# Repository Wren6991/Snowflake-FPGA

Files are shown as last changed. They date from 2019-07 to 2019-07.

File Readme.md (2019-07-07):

Snowflake FPGA HAT
==================

As an experiment, I am designing a PCB using only my Pi 4 4GB. Any other machine is off-limits. This includes

- Schematic entry
- Layout
- Datasheets and reference material
- Background Twitter browsing
- Rendering PCB glamour shots:

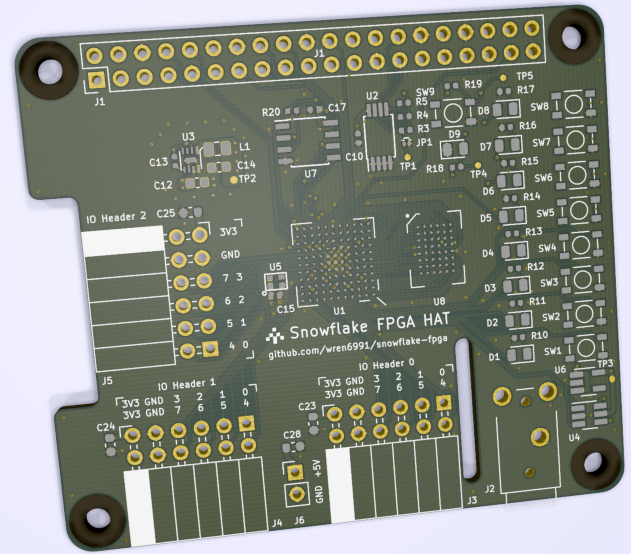
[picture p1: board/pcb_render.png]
Rendering of PCB


This is a HAT (Raspberry Pi addon board) with an iCE40 HX8k FPGA. The Pi can program the FPGA, and communicate with it via a UART, or a fast, bidirectional SDIO link. This project was spurred by the realisation that Pi 4 is a plausible FPGA development platform: faster processors, expanded memory and, above all, dramatic improvements in [Symbiotic EDA](https://www.symbioticeda.com/)'s open source design flows in the last few years.

[View schematic (PDF)](board/fpga_hat.pdf)

With the exception of the `datasheet/` directory (to which I do not lay claim), this repository is distributed under the [Apache-2.0 License](License).

Features
--------

- iCE40 HX8k
- 4 Mbit SRAM 16 bit wide, 10 ns access
- 4 Mbit flash for FPGA image and user data; dual I/O support
- 3 PMOD-compatible expansion headers
    - 8 3.3V IOs each, plus power and ground
    - 2 headers on one side, 1 on another; the two on one side have standard 0.9" spacing, allowing use of dual-PMOD boards
- Communication with host Pi:
    - UART
    - SPI for flash programming
    - SDIO for fast communications
    - FPGA reset, and configuration status (CDONE)
- 8 user pushbuttons and LEDs
- Reset button and configuration status LED
- Audio output via 3.5 mm jack (same audio circuit as Pi)

Tolerances
----------

Of the 121 balls on the FPGA's BGA package, I am using 120; the sole unconnected ball is VPP_FAST, which is used only for NVCM programming. This will make the layout exceptionally tight, which is part of the experiment! For a fighting chance, I am using JLCPCB to manufacture the prototype boards, rather than my usual iTead. Their tighter manufacturing tolerances should permit two traces between 0.3 mm pads on a 0.8 mm-pitch BGA, which allows the first 3 ranks of balls to be routed out on layer 1.

The capability requirements for this board are:

- Via drill 0.2 mm
- Via diameter 0.45 mm
- Copper min width 0.09 mm
- Copper-copper clearance 0.09 mm
- Solder mask expansion 0.05 mm

Stackup
-------

This is a 4-layer board.

- L1: signal, GND fill
- L2: GND plane
- L3: Power polygons (+5V, +3V3, +1V2)
- L4: signal, GND fill

All layers 1 oz/sqft copper. Assumed stacking for FR4 layers:

- L1-L2 0.2 mm prepreg
- L2-L3 1.2 mm core
- L3-L4 0.2 mm prepreg

These dimensions are not critical. Signal integrity will be improved by minimising separation of L1-L2, but none of the routing is impedance-controlled.

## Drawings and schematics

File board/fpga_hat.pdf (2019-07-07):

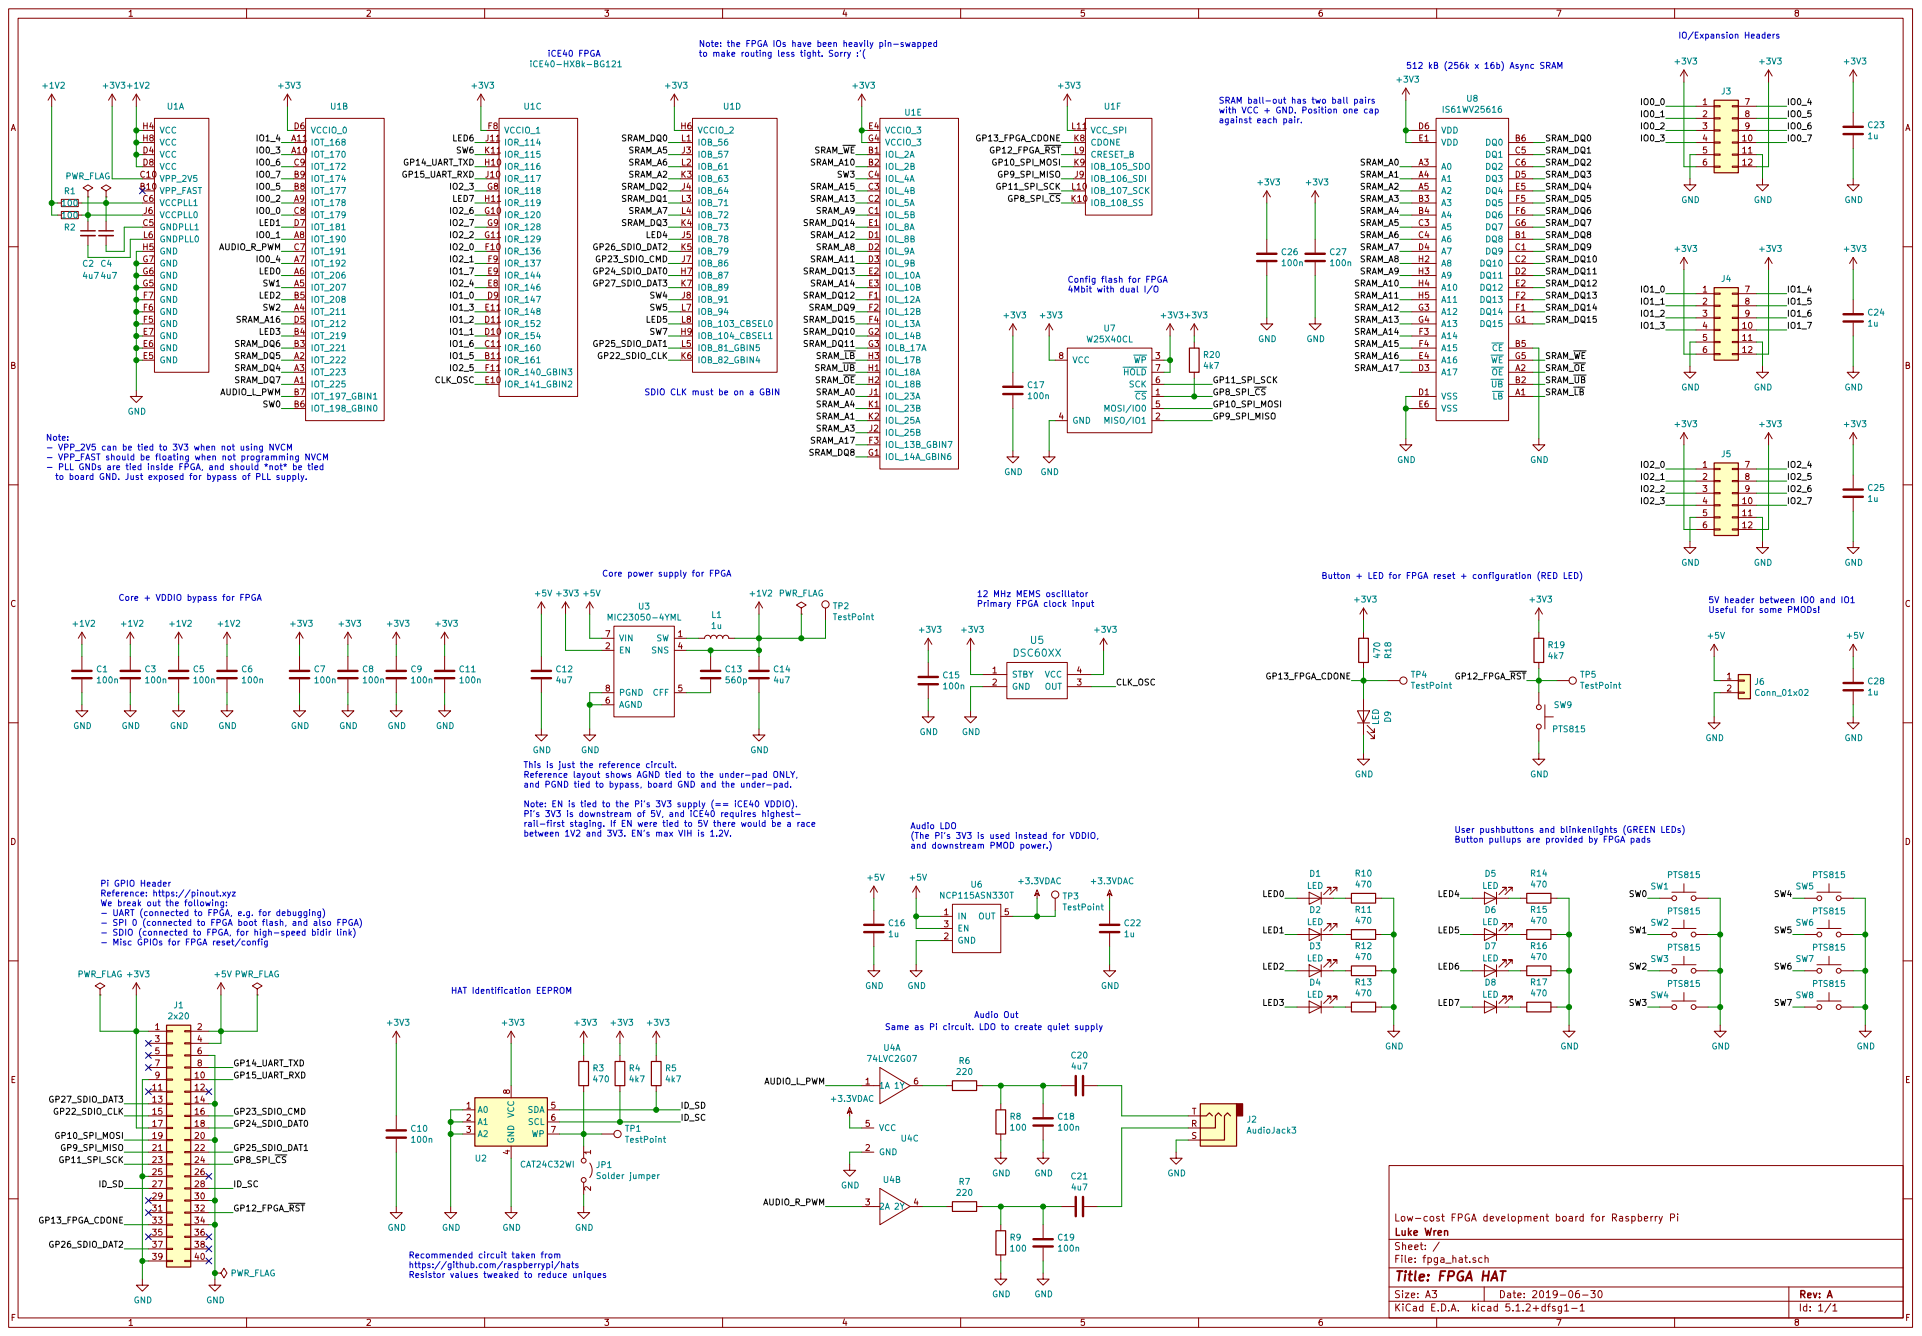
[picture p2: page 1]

to make routing less tight. Sorry :'( SDIO CLK must be on a GBIN

100n SRAM ball-out has two ball pairs
with VCC + GND. Position one cap
against each pair.

PWR_FLAG
to board GND. Just exposed for bypass of PLL supply. R1

GP11_SPI_SCK GP8_SPI_CS Config flash for FPGA
4Mbit with dual I/O
+3V3 GND

Note: - VPP_2V5 can be tied to 3V3 when not using NVCM

- VPP_FAST should be floating when not programming NVCM
- PLL GNDs are tied inside FPGA, and should *not* be tied

+1V2 Core power supply for FPGA

5V header between IO0 and IO1 Useful for some PMODs! C10

between 1V2 and 3V3. EN's max VIH is 1.2V. +5V GND

12 MHz MEMS oscillator Primary FPGA clock input
100n +3V3 GND

Reference layout shows AGND tied to the under-pad ONLY,
and PGND tied to bypass, board GND and the under-pad.

Note: EN is tied to the Pi's 3V3 supply (== iCE40 VDDIO).
Pi's 3V3 is downstream of 5V, and iCE40 requires highest-
rail-first staging. If EN were tied to 5V there would be a race

Button pullups are provided by FPGA pads Audio LDO
(The Pi's 3V3 is used instead for VDDIO,
1u +5V GND

SW4 SW5 SW6 SW7 User pushbuttons and blinkenlights (GREEN LEDs)

2x20 Pi GPIO Header Reference: https://pinout.xyz

We break out the following:
- UART (connected to FPGA, e.g. for debugging)
- SPI 0 (connected to FPGA boot flash, and also FPGA)
- SDIO (connected to FPGA, for high-speed bidir link)

4 SDA 5 SCL 6 WP 7 VCC

File: fpga_hat.sch Sheet: / Luke Wren

Recommended circuit taken from
https://github.com/raspberrypi/hats

Id: 1/1 Title: FPGA HAT

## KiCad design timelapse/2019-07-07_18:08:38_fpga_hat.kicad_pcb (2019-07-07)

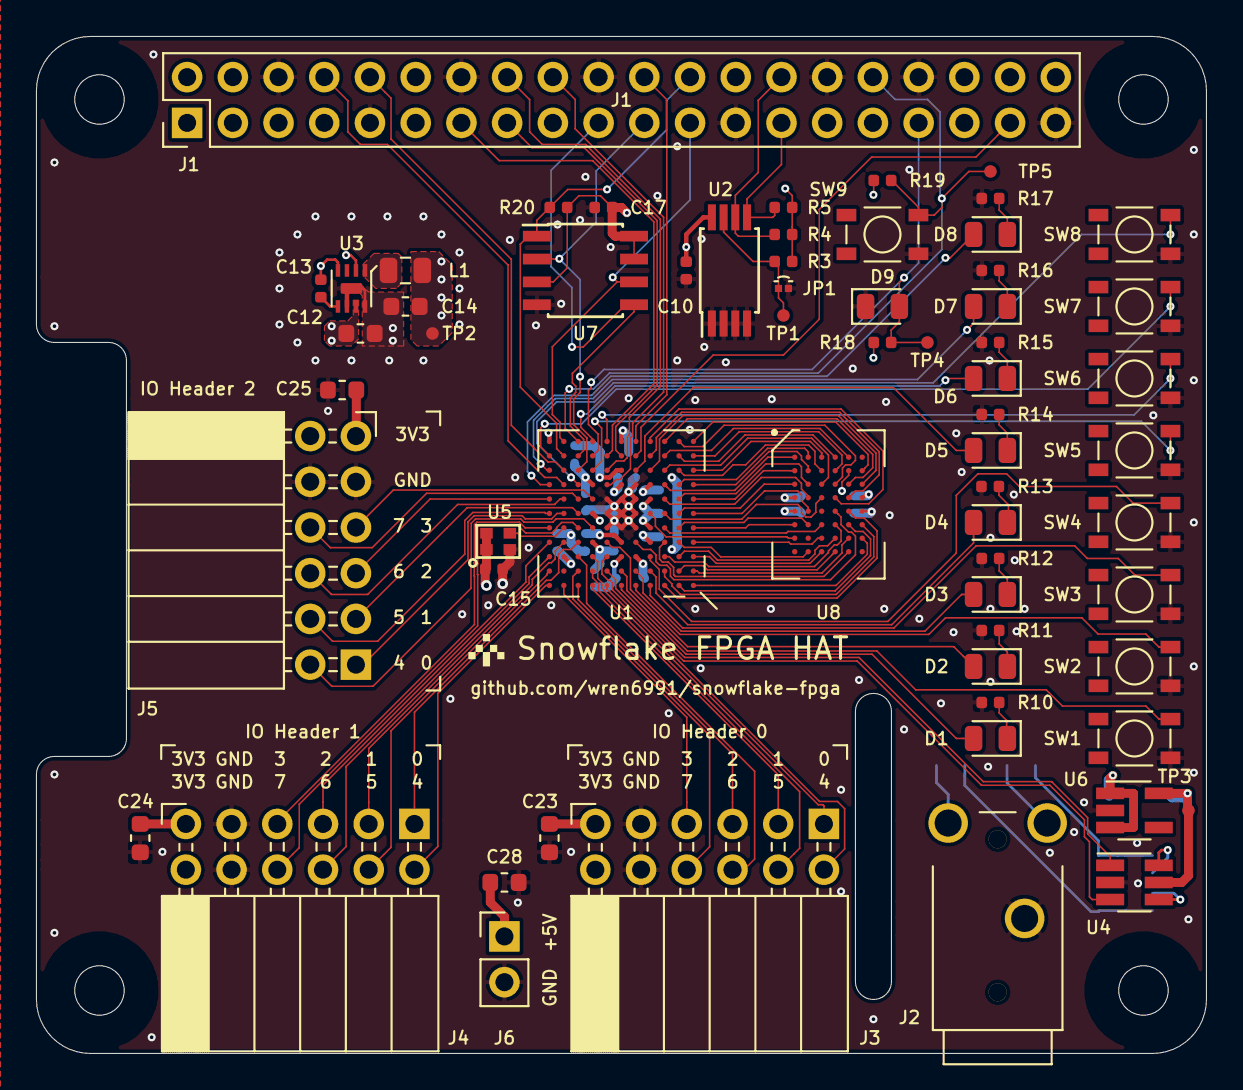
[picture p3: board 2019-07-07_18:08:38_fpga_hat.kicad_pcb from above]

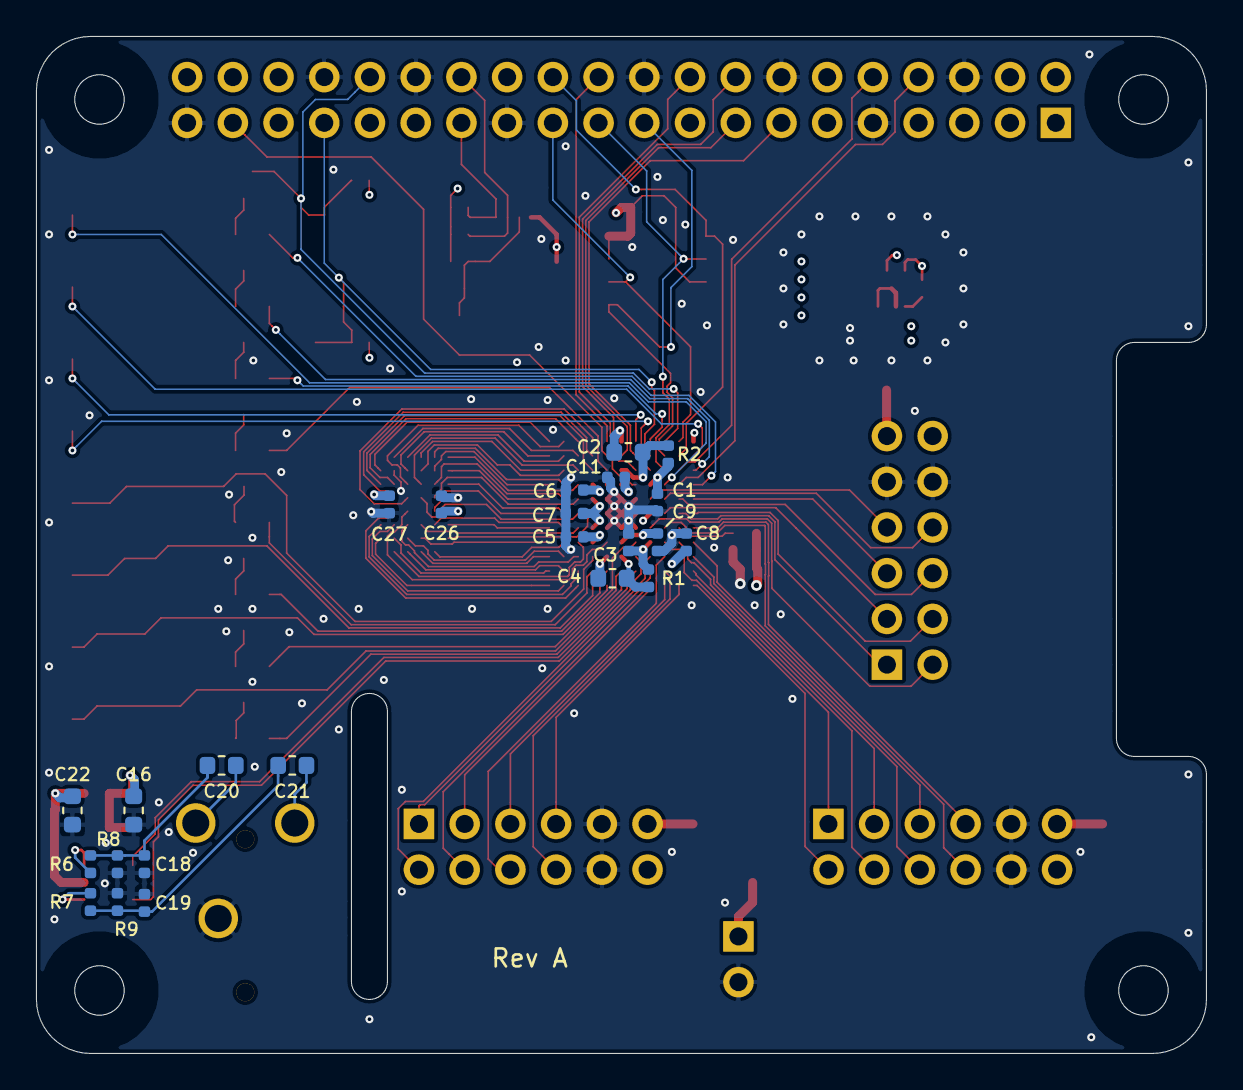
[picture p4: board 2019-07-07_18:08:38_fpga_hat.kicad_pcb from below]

Board: 4 copper layers, 65.0 x 56.5 mm, 87 parts (24 on the bottom side), 123 nets.

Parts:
C1, C3, C5, C6, C7, C8, C9, C10, C11, C15, C17, C18, C19, C26, C27: 100n; C_0402_1005Metric
C2, C4, C12, C14, C20, C21: 4u7; C_0603_1608Metric
C13: 560p; C_0402_1005Metric
C16, C22, C23, C24, C25, C28: 1u; C_0603_1608Metric
D1, D2, D3, D4, D5, D6, D7, D8, D9: LED; LED_0805_2012Metric
J1: 2x20; PinHeader_2x20_P2.54mm_Vertical
J2: AudioJack3; STX-3000_TRS_3.5mm
J3, J4, J5: Conn_02x06_Top_Bottom; PinSocket_2x06_P2.54mm_Horizontal
J6: Conn_01x02; PinHeader_1x02_P2.54mm_Vertical
JP1: Solder jumper; SOLDER_JUMP
L1: 1u; L_0805_2012Metric
R1, R2, R8, R9: 100; R_0402_1005Metric
R3, R10, R11, R12, R13, R14, R15, R16, R17, R18: 470; R_0402_1005Metric
R4, R5, R19, R20: 4k7; R_0402_1005Metric
R6, R7: 220; R_0402_1005Metric
SW1, SW2, SW3, SW4, SW5, SW6, SW7, SW8, SW9: PTS815
TP1, TP2, TP3, TP4, TP5: TestPoint; Testpoint_d0.7mm
U1: iCE40-HX8k-BG121; BGA-121_11x11_9.0x9.0mm
U2: CAT24C32WI; TSSOP-8_4.4x3mm_P0.65mm
U3: MIC23050-4YML; DFN8_2x2_0.5mm
U4: 74LVC2G07; SOT-23-6_Handsoldering
U5: DSC60XX; LGA4_1.6x1.2mm
U6: NCP115ASN330T; SOT-23-5_HandSoldering
U7: W25X40CL; SOIC-8_3.9x4.9mm_P1.27mm
U8: IS61WV25616; BGA-48_6x8_6.0x8.0mm

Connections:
+1V2: C1.1, C3.1, C5.1, C6.1, C13.1, C14.1, L1.2, R1.2, R2.2, TP2.1, U1.D4, U1.D8, U1.H4, U1.H8, U3.4
+3.3VDAC: C22.1, TP3.1, U4.5, U6.5
+3V3: C7.1, C8.1, C9.1, C10.1, C11.1, C15.1, C17.1, C23.1, C24.1, C25.1, C26.1, C27.1, J1.1, J1.17, J3.6, J3.12, J4.6, J4.12, J5.6, J5.12, R3.1, R4.1, R5.1, R18.2, R19.1, R20.1, U1.C10, U1.D6, U1.E4, U1.F8, U1.G4, U1.H6, U1.L11, U2.8, U5.1, U5.4, U7.3, U7.7, U7.8, U8.D6, U8.E1
+5V: C12.1, C16.1, C28.1, J1.2, J1.4, J6.1, U3.2, U3.7, U6.1, U6.3
/AUDIO_L_PWM: U1.B7, U4.1
/AUDIO_R_PWM: U1.C7, U4.3
/CLK_OSC: U1.E10, U5.3
/GP8_SPI_~CS: J1.24, R20.2, U1.K10, U7.1
/GP9_SPI_MISO: J1.21, U1.J9, U7.2
/GP10_SPI_MOSI: J1.19, U1.K9, U7.5
/GP11_SPI_SCK: J1.23, U1.L10, U7.6
/GP12_FPGA_~RST: J1.32, R19.2, SW9.1, TP5.1, U1.L9
/GP13_FPGA_CDONE: D9.2, J1.33, R18.1, TP4.1, U1.K8
/GP14_UART_TXD: J1.8, U1.H10
/GP15_UART_RXD: J1.10, U1.J10
/GP22_SDIO_CLK: J1.15, U1.K6
/GP23_SDIO_CMD: J1.16, U1.J7
/GP24_SDIO_DAT0: J1.18, U1.H7
/GP25_SDIO_DAT1: J1.22, U1.L5
/GP26_SDIO_DAT2: J1.37, U1.K5
/GP27_SDIO_DAT3: J1.13, U1.K7
/ID_SC: J1.28, R4.2, U2.6
/ID_SD: J1.27, R5.2, U2.5
/IO0_0: J3.1, U1.C8
/IO0_1: J3.2, U1.A8
/IO0_2: J3.3, U1.A9
/IO0_3: J3.4, U1.A10
/IO0_4: J3.7, U1.A7
/IO0_5: J3.8, U1.B8
/IO0_6: J3.9, U1.C9
/IO0_7: J3.10, U1.B9
/IO1_0: J4.1, U1.D9
/IO1_1: J4.2, U1.D10
/IO1_2: J4.3, U1.D11
/IO1_3: J4.4, U1.E11
/IO1_4: J4.7, U1.A11
/IO1_5: J4.8, U1.B11
/IO1_6: J4.9, U1.C11
/IO1_7: J4.10, U1.E9
/IO2_0: J5.1, U1.F10
/IO2_1: J5.2, U1.F9
/IO2_2: J5.3, U1.G11
/IO2_3: J5.4, U1.G8
/IO2_4: J5.7, U1.E8
/IO2_5: J5.8, U1.F11
/IO2_6: J5.9, U1.G10
/IO2_7: J5.10, U1.G9
/LED0: D1.2, U1.A6
/LED1: D2.2, U1.D7
/LED2: D3.2, U1.B5
/LED3: D4.2, U1.B4
/LED4: D5.2, U1.J5
/LED5: D6.2, U1.L8
/LED6: D7.2, U1.J11
/LED7: D8.2, U1.H11
/SRAM_A0: U1.J1, U8.A3
/SRAM_A1: U1.K2, U8.A4
/SRAM_A2: U1.K3, U8.A5
/SRAM_A3: U1.J2, U8.B3
/SRAM_A4: U1.K1, U8.B4
/SRAM_A5: U1.J3, U8.C3
/SRAM_A6: U1.L2, U8.C4
/SRAM_A7: U1.L4, U8.D4
/SRAM_A8: U1.D2, U8.H2
/SRAM_A9: U1.C1, U8.H3
/SRAM_A10: U1.B2, U8.H4
/SRAM_A11: U1.D3, U8.H5
/SRAM_A12: U1.D1, U8.G3
/SRAM_A13: U1.C2, U8.G4
/SRAM_A14: U1.E3, U8.F3
/SRAM_A15: U1.C3, U8.F4
/SRAM_A16: U1.D5, U8.E4
/SRAM_A17: U1.F3, U8.D3
/SRAM_DQ0: U1.L1, U8.B6
/SRAM_DQ1: U1.L3, U8.C5
/SRAM_DQ2: U1.J4, U8.C6
/SRAM_DQ3: U1.K4, U8.D5
/SRAM_DQ4: U1.A3, U8.E5
/SRAM_DQ5: U1.A2, U8.F5
/SRAM_DQ6: U1.B3, U8.F6
/SRAM_DQ7: U1.A1, U8.G6
/SRAM_DQ8: U1.G1, U8.B1
/SRAM_DQ9: U1.F2, U8.C1
/SRAM_DQ10: U1.G2, U8.C2
/SRAM_DQ11: U1.G3, U8.D2
/SRAM_DQ12: U1.F1, U8.E2
/SRAM_DQ13: U1.E2, U8.F2
/SRAM_DQ14: U1.E1, U8.F1
/SRAM_DQ15: U1.F4, U8.G1
/SRAM_~LB: U1.H3, U8.A1
/SRAM_~OE: U1.H2, U8.A2
/SRAM_~UB: U1.H1, U8.B2
/SRAM_~WE: U1.B1, U8.G5
/SW0: SW1.1, U1.B6
/SW1: SW2.1, U1.A5
/SW2: SW3.1, U1.A4
/SW3: SW4.1, U1.C4
/SW4: SW5.1, U1.J8
/SW5: SW6.1, U1.L7
/SW6: SW7.1, U1.K11
/SW7: SW8.1, U1.H9
GND: C1.2, C3.2, C5.2, C6.2, C7.2, C8.2, C9.2, C10.2, C11.2, C12.2, C14.2, C15.2, C16.2, C17.2, C18.2, C19.2, C22.2, C23.2, C24.2, C25.2, C26.2, C27.2, C28.2, D9.1, J1.6, J1.9, J1.14, J1.20, J1.25, J1.30, J1.34, J1.39, J2.S, J3.5, J3.11, J4.5, J4.11, J5.5, J5.11, J6.2, JP1.2, R8.2, R9.2, R10.1, R11.1, R12.1, R13.1, R14.1, R15.1, R16.1, R17.1, SW1.2, SW2.2, SW3.2, SW4.2, SW5.2, SW6.2, SW7.2, SW8.2, SW9.2, U1.E5, U1.E6, U1.E7, U1.F5, U1.F6, U1.F7, U1.G5, U1.G6, U1.G7, U1.H5, U2.1, U2.2, U2.3, U2.4, U3.6, U3.8, U4.2, U5.2, U6.2, U7.4, U8.B5, U8.D1, U8.E6
unnamed: C2.1, R2.1, U1.J6
unnamed: C2.2, U1.L6
unnamed: C4.1, R1.1, U1.C6
unnamed: C4.2, U1.C5
unnamed: C13.2, U3.5
unnamed: C18.1, C20.2, R6.1, R8.1
unnamed: C19.1, C21.2, R7.1, R9.1
unnamed: C20.1, J2.T
unnamed: C21.1, J2.R
unnamed: D1.1, R10.2
unnamed: D2.1, R11.2
unnamed: D3.1, R12.2
unnamed: D4.1, R13.2
unnamed: D5.1, R14.2
unnamed: D6.1, R15.2
unnamed: D7.1, R16.2
unnamed: D8.1, R17.2
unnamed: JP1.1, R3.2, TP1.1, U2.7
unnamed: L1.1, U3.1
unnamed: R6.2, U4.6
unnamed: R7.2, U4.4

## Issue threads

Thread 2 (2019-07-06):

Consider renaming to wren-ice40-hat or wren-fpga-hat

mithro, 2019-07-06:
This is a cool little board but it has a name collision with a lot of other FPGA RPi hats. Any chance you would consider renaming it to be slightly less generic? `wren-fpga-hat` or `wren-ice40-hat` would both be great!

Wren6991, 2019-07-07:
At your special request this is now called `Snowflake FPGA HAT`

mithro, 2019-07-07:
Great name! Thank you!

Closed 2019-07-07.

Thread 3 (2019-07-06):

Steal Fomu EVT RPi based programming tool?

mithro, 2019-07-06:
The Fomu EVT boards where RPi based Hats tool. Thus @xobs wrote a great little tool for bitbanging SPI to program the iCE40 and SPI on the board (even supports things like QPI mode!).

Take a look at https://github.com/im-tomu/fomu-flash - more than happy to add your board as a target option.

(There is also a tool which builds a RPi image with all the ice40 tooling at https://github.com/im-tomu/fomu-pi-gen too.)

Wren6991, 2019-07-07:
I rather wanted the fun of doing this myself! :cry: Thank you for the link to the tools, they look handy. If I end up modifying these then I will submit a PR.

Is there an advantage of the Fomu ROM patching vs `icebram`?

xobs, 2019-07-08:
The advantage to the Fomu ROM patching vs `icebram` is that it's less to keep track of, and ends up being faster:

* `icebram` requires an input ROM, an output ROM, an input hexfile, and an input binary. Foboot just requires an input ROM and an input binary.
* The `icebram` hexfile needs to be in a specific order, and I ended up needing to come up with additional tools to massage the bitstream into the correct format. `fomu-flash` works on binary images.
* `fomu-flash` is near-instant, whereas `icebram` took several seconds

In the end, both accomplish the same thing, so if you're already using `icebram` then there's no need to change.

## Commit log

2019-06-29 Probably time for another commit :)
    [fpga_hat.sch]
2019-06-29 Add SRAM BGA footprint, and add it to schematic
    [fpga_hat.sch]
2019-06-29 Add switches and LEDs
    [fpga_hat.sch]
2019-06-30 Add datasheet for SRAM, core regulator. Add core regulator to schematic. Some tidy-up.
    [fpga_hat.sch]
2019-06-30 Add more datasheets. Add FPGA decoupling. Add button + LED for FPGA RST/CDONE
    [fpga_hat.sch]
2019-06-30 Add config flash, fix some ERC errors
    [fpga_hat.sch]
2019-06-30 Review schematic and symbols against datasheets; minor corrections. ERC is now clean.
2019-06-30 Add footprints for FPGA, SRAM, SMPS. Do some footprint association.
    [fpga_hat.sch]
2019-06-30 More footprints
    [fpga_hat.sch]
2019-07-01 Footprints 100%
    [fpga_hat.sch]
2019-07-01 Add Readme and schematic PDF
2019-07-01 Board outline, mounting holes, slot
2019-07-01 Add new footprint for PMOD connectors, with correct pin numbering
    [fpga_hat.kicad_pcb, fpga_hat.sch]
2019-07-01 Add footprint for new, smaller tact switch. Add some datasheets
    [fpga_hat.sch]
2019-07-02 Add 5V header to schematic -- useful for some PMODs. Move camera slot 1.5mm to right, to leave room for PMODs.
    [fpga_hat.kicad_pcb, fpga_hat.sch]
2019-07-02 Start placing components
    [2019-07-02_12:26:12_fpga_hat.kicad_pcb, 2019-07-02_12:31:57_fpga_hat.kicad_pcb, 2019-07-02_12:40:42_fpga_hat.kicad_pcb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]
2019-07-02 All parts on board
    [2019-07-02_13:30:37_fpga_hat.kicad_pcb, 2019-07-02_13:30:45_fpga_hat.kicad_pcb, 2019-07-02_13:46:31_fpga_hat.kicad_pcb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]
2019-07-02 First run at power planes under FPGA
    [2019-07-02_15:37:51_fpga_hat.kicad_pcb, 2019-07-02_15:37:58_fpga_hat.kicad_pcb, 2019-07-02_15:42:42_fpga_hat.kicad_pcb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]
2019-07-02 Nobody cares about your return code inotify
    [2019-07-02_16:02:18_fpga_hat.kicad_pcb, 2019-07-02_16:02:29_fpga_hat.kicad_pcb, 2019-07-02_17:02:16_fpga_hat.kicad_pcb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]
2019-07-02 Start BGA escape
    [fpga_hat.kicad_pcb]
2019-07-02 Continue FPGA escape. Start escaping SRAM.
    [2019-07-02_17:07:43_fpga_hat.kicad_pcb, 2019-07-02_17:08:03_fpga_hat.kicad_pcb, 2019-07-02_17:57:29_fpga_hat.kicad_pcb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]
2019-07-02 SRAM escaped. Some work on FPGA power routing. Some SRAM pinswapping.
    [2019-07-02_18:15:30_fpga_hat.kicad_pcb, 2019-07-02_18:15:46_fpga_hat.kicad_pcb, 2019-07-02_18:19:44_fpga_hat.kicad_pcb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]
2019-07-02 More FPGA escape
    [2019-07-02_20:54:50_fpga_hat.kicad_pcb, 2019-07-02_20:55:29_fpga_hat.kicad_pcb, 2019-07-02_21:04:22_fpga_hat.kicad_pcb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]
2019-07-03 Continue BGA route-out. SRAM connected, start heading out toward LEDs and IO.
    [2019-07-02_21:45:36_fpga_hat.kicad_pcb, 2019-07-02_21:45:48_fpga_hat.kicad_pcb, 2019-07-03_06:45:34_fpga_hat.kicad_pcb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]
2019-07-03 Continue routing
    [2019-07-03_07:15:18_fpga_hat.kicad_pcb, 2019-07-03_07:15:47_fpga_hat.kicad_pcb, 2019-07-03_17:17:01_fpga_hat.kicad_pcb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]
2019-07-05 Connect up SDIO, remaining buttons + LEDs.
    [2019-07-03_18:35:03_fpga_hat.kicad_pcb, 2019-07-03_18:35:23_fpga_hat.kicad_pcb, 2019-07-05_20:45:15_fpga_hat.kicad_pcb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]
2019-07-06 Start fixing up planes
    [2019-07-05_22:15:04_fpga_hat.kicad_pcb, 2019-07-05_22:15:17_fpga_hat.kicad_pcb, 2019-07-05_22:26:53_fpga_hat.kicad_pcb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]
2019-07-06 Routed 100%
    [2019-07-06_11:05:02_fpga_hat.kicad_pcb, 2019-07-06_11:05:10_fpga_hat.kicad_pcb, 2019-07-06_11:24:12_fpga_hat.kicad_pcb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]
2019-07-06 Clean up minor DRC
    [2019-07-06_12:29:16_fpga_hat.kicad_pcb, 2019-07-06_12:29:23_fpga_hat.kicad_pcb, 2019-07-06_12:41:44_fpga_hat.kicad_pcb]
2019-07-06 Tidy up L1 silkscreen
    [2019-07-06_12:42:01_fpga_hat.kicad_pcb, 2019-07-06_12:42:14_fpga_hat.kicad_pcb, 2019-07-06_12:52:32_fpga_hat.kicad_pcb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]
2019-07-06 Tidy up both silkscreen layers. Remove copper from mounting hole screw lands.
    [2019-07-06_13:02:27_fpga_hat.kicad_pcb, 2019-07-06_13:02:35_fpga_hat.kicad_pcb, 2019-07-06_13:25:29_fpga_hat.kicad_pcb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]
2019-07-07 Add pinout on silkscreen, move TP5
    [2019-07-06_13:41:26_fpga_hat.kicad_pcb, 2019-07-06_13:41:27_fpga_hat.kicad_pcb, 2019-07-07_12:53:39_fpga_hat.kicad_pcb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]
2019-07-07 Tidy up SRAM escape and decoupling
    [2019-07-07_13:19:32_fpga_hat.kicad_pcb, 2019-07-07_13:19:51_fpga_hat.kicad_pcb, 2019-07-07_13:36:48_fpga_hat.kicad_pcb]
2019-07-07 Re-render PDF schematic
    [2019-07-07_13:37:36_fpga_hat.kicad_pcb]
2019-07-07 Fix small silkscreen error, improve ground stitching and core supply layout
    [2019-07-07_17:06:08_fpga_hat.kicad_pcb, 2019-07-07_17:06:09_fpga_hat.kicad_pcb, 2019-07-07_17:15:56_fpga_hat.kicad_pcb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]
2019-07-07 Rename board. Some silkscreen tweaks.
    [2019-07-07_17:33:00_fpga_hat.kicad_pcb, 2019-07-07_17:33:20_fpga_hat.kicad_pcb, 2019-07-07_18:07:42_fpga_hat.kicad_pcb]
2019-07-07 Move core VDD enable to +3V3 to improve power supply staging
    [2019-07-07_18:08:38_fpga_hat.kicad_pcb, 2019-07-07_18:25:46_fpga_hat.kicad_pcb, fpga_hat.sch]
